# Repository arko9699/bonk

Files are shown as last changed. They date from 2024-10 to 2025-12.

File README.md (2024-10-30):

# bonk
 A 40% keyboard PCB project

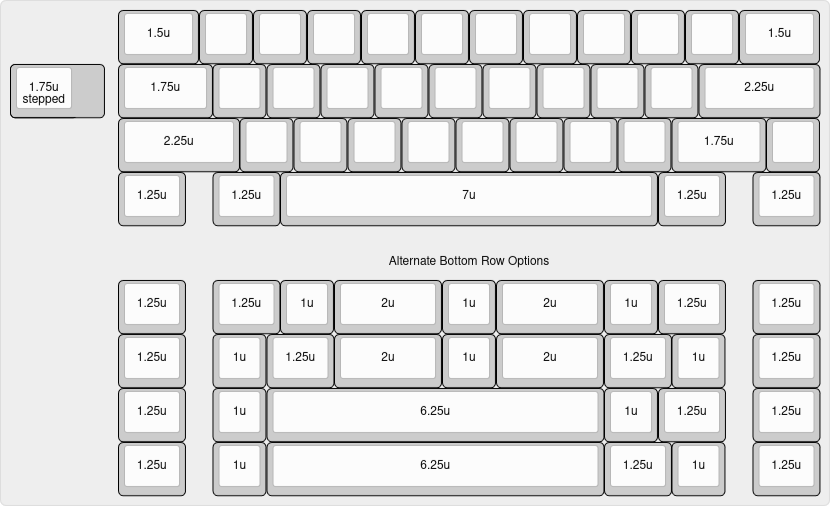
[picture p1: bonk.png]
layouts


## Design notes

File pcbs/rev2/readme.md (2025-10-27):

# PCB
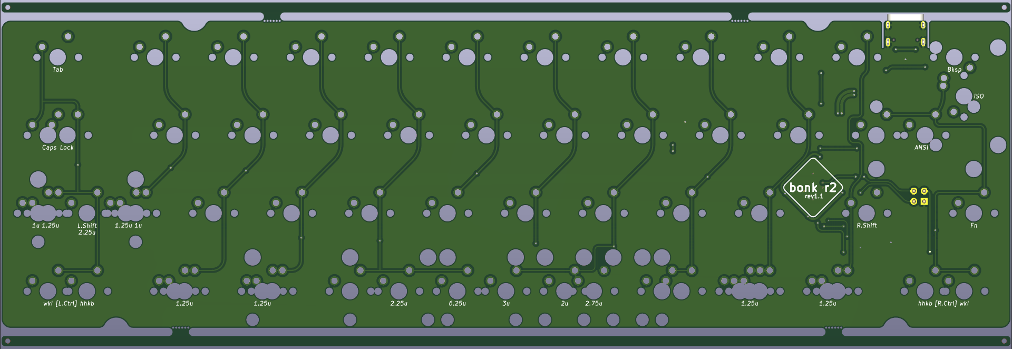
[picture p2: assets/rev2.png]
PCB


# Supported Layouts
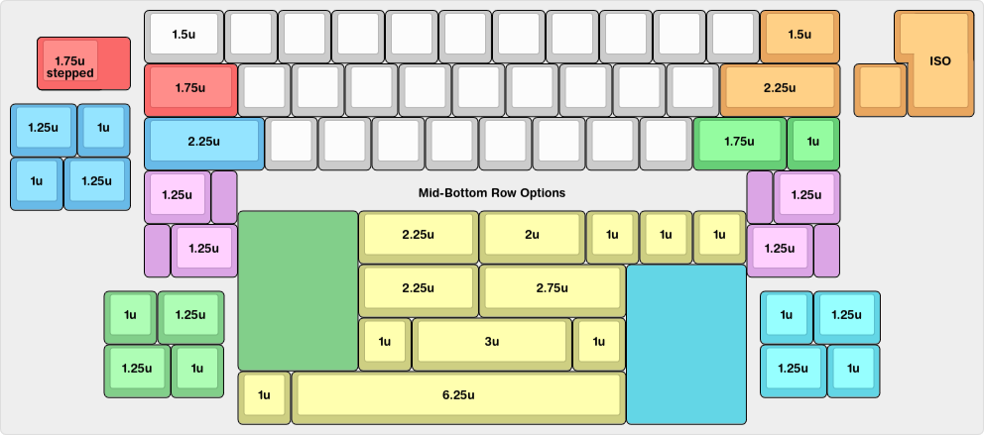
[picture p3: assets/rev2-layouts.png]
Supported Layouts


# Opening the project
* Atleast KiCAD 9.0.2 is required to open the project properly. Older versions of KiCAD will not work.
* [marbastlib](https://github.com/ebastler/marbastlib) was used for some of the footprints.

# Flashing
The following steps assume you have a PCB and the latest rev2 firmware downloaded.

Common Steps:
1. Plug in the PCB to the computer using an USB cable (either using uDB or directly)
2. Use [QMK Toolbox](https://qmk.fm/toolbox) on [Windows/Mac](https://docs.qmk.fm/newbs_flashing#flashing-your-keyboard-with-qmk-toolbox). Only CLI method is supported on [Linux](https://docs.qmk.fm/flashing#stm32-apm32-dfu). Select the 'bin' firmware file on your disk.
3. Hold down button for approximately 10 seconds to enter bootloader.
4. Select the 'Flash' option and wait for some time. The PCB should restart automatically after flashing and be ready to use.
5. Open [vial](https://vial.rocks/) in a USB HID supported browser (Chrome/Edge/Brave etc.) to modify your keymap.

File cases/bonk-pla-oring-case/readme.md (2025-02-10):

# What you'll need

1. The case (ofc)
2. Option A :
      * An MX switch plate (dxf given at the top directory may be used as is)
      * Gummy O-ring (similar to the ones used by [Bakeneko](https://github.com/kkatano/bakeneko-60)), recommended dimensions are 143mm ID, 3.53mm CS
     
   Option B : Use [EagleVee's Plateless O-Ring Kit](https://github.com/EagleVee/keyboards/tree/master/oring-plateless-kit) for a plateless experience

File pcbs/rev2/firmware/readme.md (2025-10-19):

# bonkr2

* Keyboard Maintainer: [Arko9699](https://github.com/arko9699)
* Hardware Supported: stm32f072
* Hardware Availability: [Github](https://github.com/arko9699/bonk/tree/main/pcbs/rev2)

Make example for this keyboard (after setting up your build environment):

    make arko/bonkr2:default

Flashing example for this keyboard:

    make arko/bonkr2:default:flash

See the [build environment setup](https://docs.qmk.fm/#/getting_started_build_tools) and the [make instructions](https://docs.qmk.fm/#/getting_started_make_guide) for more information. Brand new to QMK? Start with our [Complete Newbs Guide](https://docs.qmk.fm/#/newbs).

## Bootloader

Enter the bootloader in 3 ways:

* **Bootmagic reset**: Hold down the key at (0,0) in the matrix (usually the top left key or Escape) and plug in the keyboard
* **Physical reset button**: Briefly press the button on the back of the PCB - some may have pads you must short instead
* **Keycode in layout**: Press the key mapped to `QK_BOOT` if it is available

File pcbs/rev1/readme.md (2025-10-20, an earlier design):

# PCB
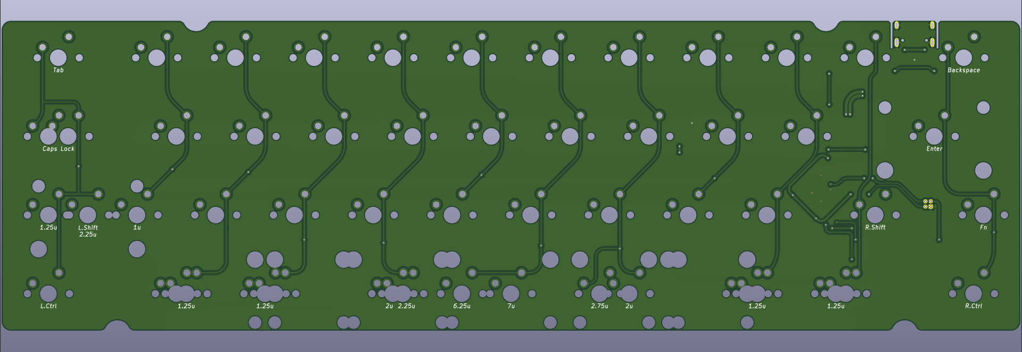
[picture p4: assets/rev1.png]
PCB


# Supported Layouts
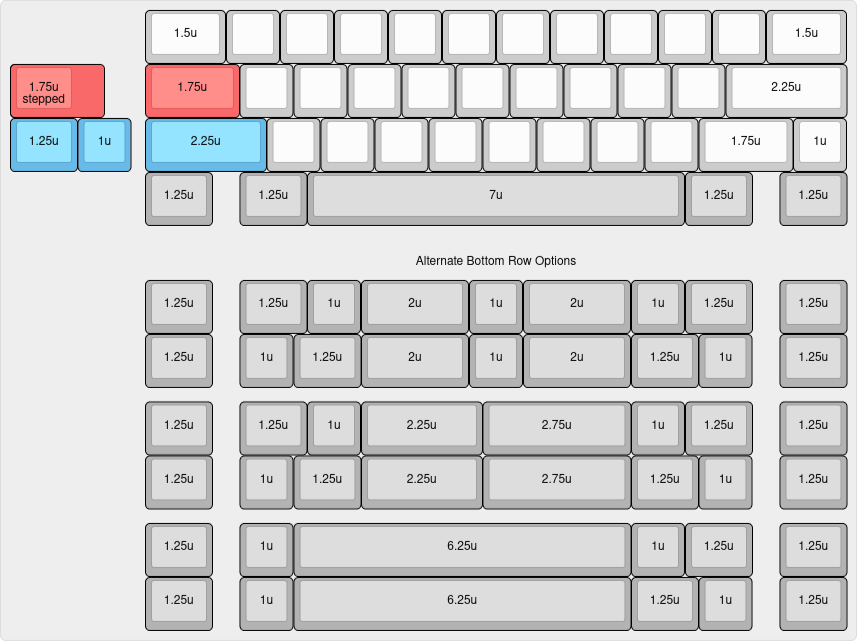
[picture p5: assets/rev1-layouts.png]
Supported Layouts


# Opening the project
* Atleast KiCAD 8.0.7 is required to open the project properly. Older versions of KiCAD will not work.
* [marbastlib](https://github.com/ebastler/marbastlib) was used for some of the footprints.

# Bill of Materials
|LCSC #  |Description|Value |Package |Amount|Comments |
|---|---|---|---|---|---|
|C15195  |Capacitor  |10nF |0402 |1 | |
|C1525 |Capacitor  |100nF |0402 |4 | |
|C15849  |Capacitor  |1uF |0603 |3 | |
|C19666  |Capacitor  |4.7uF |0603 |2 | |
|C25076  |Resistor |100Ω |0402 |1 | |
|C21190  |Resistor |1k Ω |0603 |1 |Added in rev1.1 |
|C23186  |Resistor |5.1kΩ |0603 |2 | |
|C25804  |Resistor |10kΩ |0603 |1 |Added in rev1.1 |
|C17629  |Resistor |330kΩ |0805 |1 |Added in rev1.1 |
|C17629  |Resistor |1MΩ |0805 |1 |Added in rev1.1 |
|C269104 |Fuse |500mA |0805 |1 | |
|C2988369|USB-C Port |USB-7010ASV |SMD/THT |1 | |
|C318884 |Push Button|TS-1187A |SMD |1 | |
|C5180249|ESD Prot.  |USBLC6-2SC6 |SOT-23-6|1 | |
|C81598  |Diode |1N4148W |SOD-123 |45 |Additional diode added in rev1.1|
|C81720  |MCU |STM32F072CBTx |LQFP-48 |1 | |
|C8545 |MOSFET |2N7002 |SOT-23  |1 |Added in rev1.1 |
|C5180249|Volt. Regu.|XC6206P332MR-G|SOT-23-3|1 | |
|C160404 |Opt. JST |SM04B-SRSS-TB |SMD |1 | | 

# Flashing
The following steps assume you have a PCB and the latest rev1.x firmware downloaded.

Common Steps:
1. Plug in the PCB to the computer using an USB cable (either using uDB or directly)
2. Hold down button for approximately 10 seconds to enter bootloader.
3. Use [QMK Toolbox](https://qmk.fm/toolbox) on [Windows/Mac](https://docs.qmk.fm/newbs_flashing#flashing-your-keyboard-with-qmk-toolbox). Only CLI method is supported on [Linux](https://docs.qmk.fm/flashing#stm32-apm32-dfu).
4. The PCB should restart automatically after flashing and be ready to use.
5. Open [vial](https://vial.rocks/) in a USB HID supported browser (Chrome/Edge/Brave etc.) to modify your keymap.

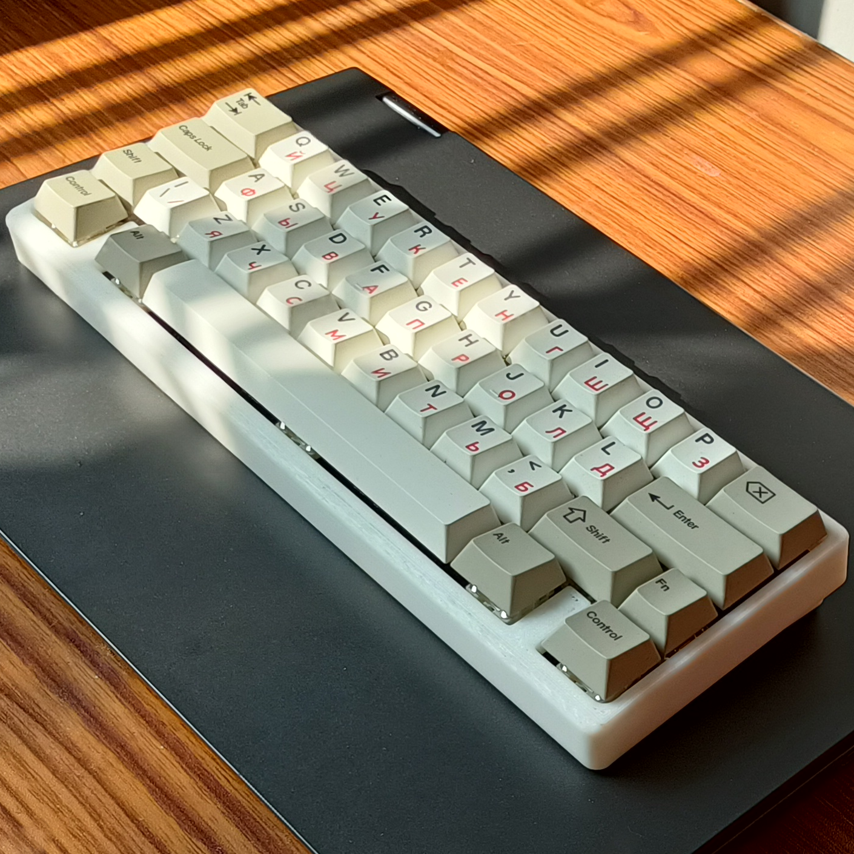
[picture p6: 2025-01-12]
assets/pic1-by-arko.png

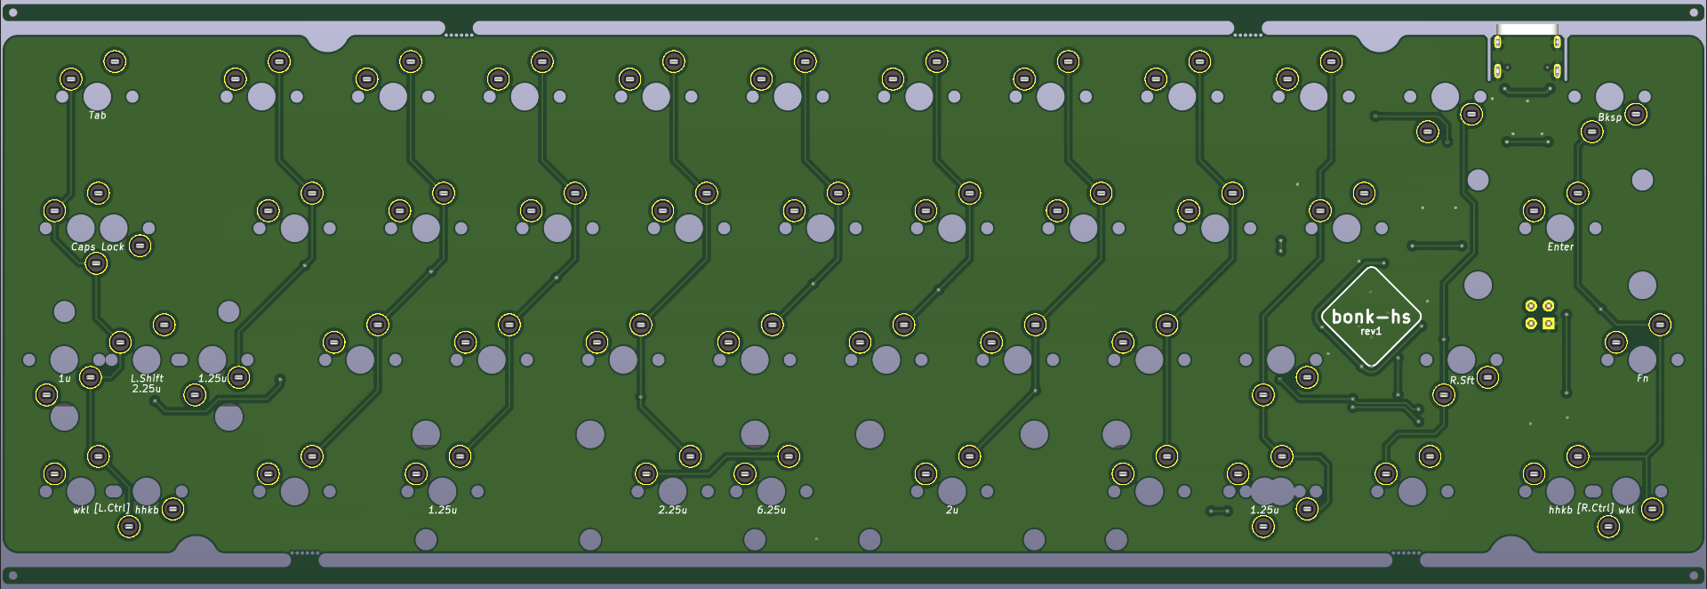
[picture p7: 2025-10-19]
assets/hotswap.png

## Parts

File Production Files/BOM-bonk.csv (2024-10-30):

Comment | Designator | Footprint | LCSC | Quantity
10n | C6 | C_0402_1005Metric | C15195 | 1
100n | C1,C10,C2,C4 | C_0402_1005Metric | C1525 | 4
Conn_01x04 | J1 | JST_SH_SM04B-SRSS-TB_1x04-1MP_P1.00mm_Horizontal | C160404 | 1
4.7u | C3,C5 | C_0603_1608Metric | C19666 | 2
10k | R1 | R_0603_1608Metric | C25744 | 1
SW_Push | SW1 | SW_Push_1P1T_XKB_TS-1187A | C318884 | 1
XC6206PxxxMR | U1 | SOT-23-3 | C5148692 | 1
4.7u | C7,C8,C9 | C_0603_1608Metric | C52923 | 3
1N4148W | D1,D10,D11,D12,D13,D14,D15,D16,D17,D18,D19,D2,D20,D21,D22,D23,D24,D25,D26,D27,D28,D29,D3,D30,D31,D32,D33,D34,D35,D36,D37,D38,D39,D4,D40,D5,D6,D7,D8,D9 | D_SOD-123 | C7420318 | 40
STM32F072CBTx | U2 | LQFP-48_7x7mm_P0.5mm | C81720 | 1
1N4148W | D41 | D_SOD-123 |  | 1
1N4148W | D42 | D_SOD-123 |  | 1
1N4148W | D44 | D_SOD-123 |  | 1
1N4148W | D43 | D_SOD-123 |  | 1

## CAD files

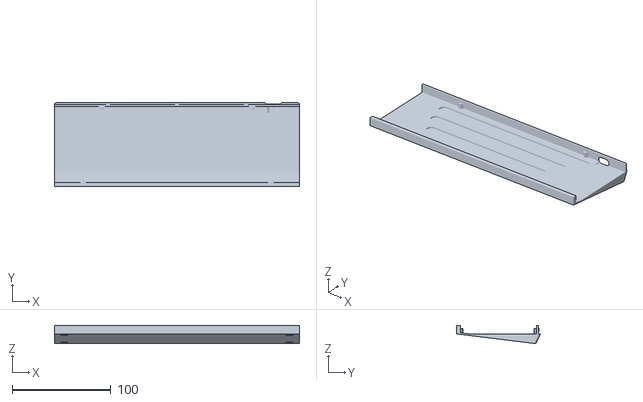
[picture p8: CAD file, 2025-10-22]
cases/bonk-pla-oring-case/bonk-pla-case-bottom.stl
248.6 x 84.9 x 18.6

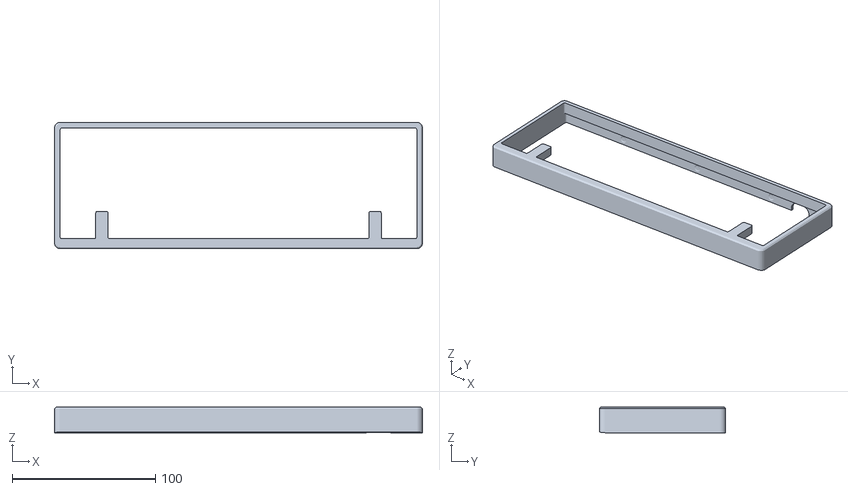
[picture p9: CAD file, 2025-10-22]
cases/bonk-pla-oring-case/bonk-pla-case-wkl-top.stl
256.6 x 88.2 x 17.8

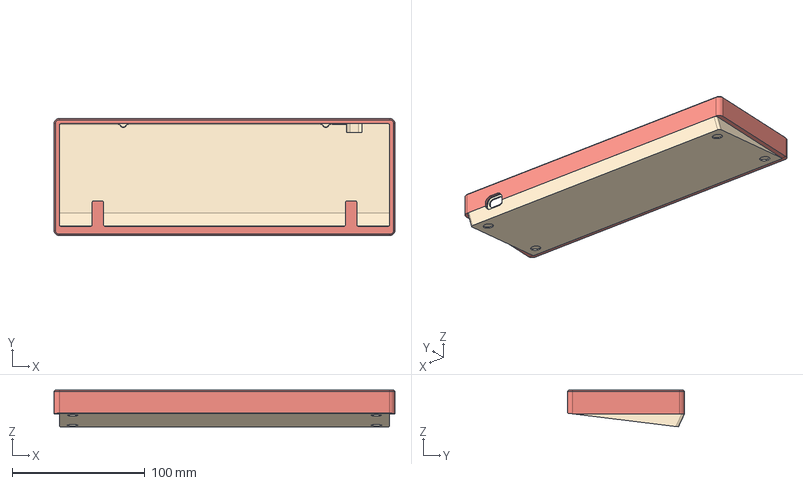
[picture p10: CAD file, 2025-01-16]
cases/bonk-pla-oring-case/bonk-pla-case.step
256.6 x 88.2 x 27.6 mm

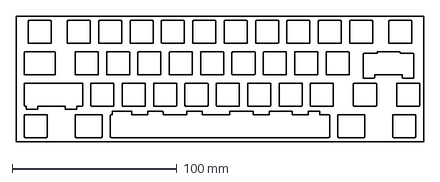
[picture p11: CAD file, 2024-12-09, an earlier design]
pcbs/rev1/bonk-plate-template.dxf
247.7 x 76.2 mm

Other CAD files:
cases/bonk-pla-oring-case/bonk-pla-case-hhkb-top.stl

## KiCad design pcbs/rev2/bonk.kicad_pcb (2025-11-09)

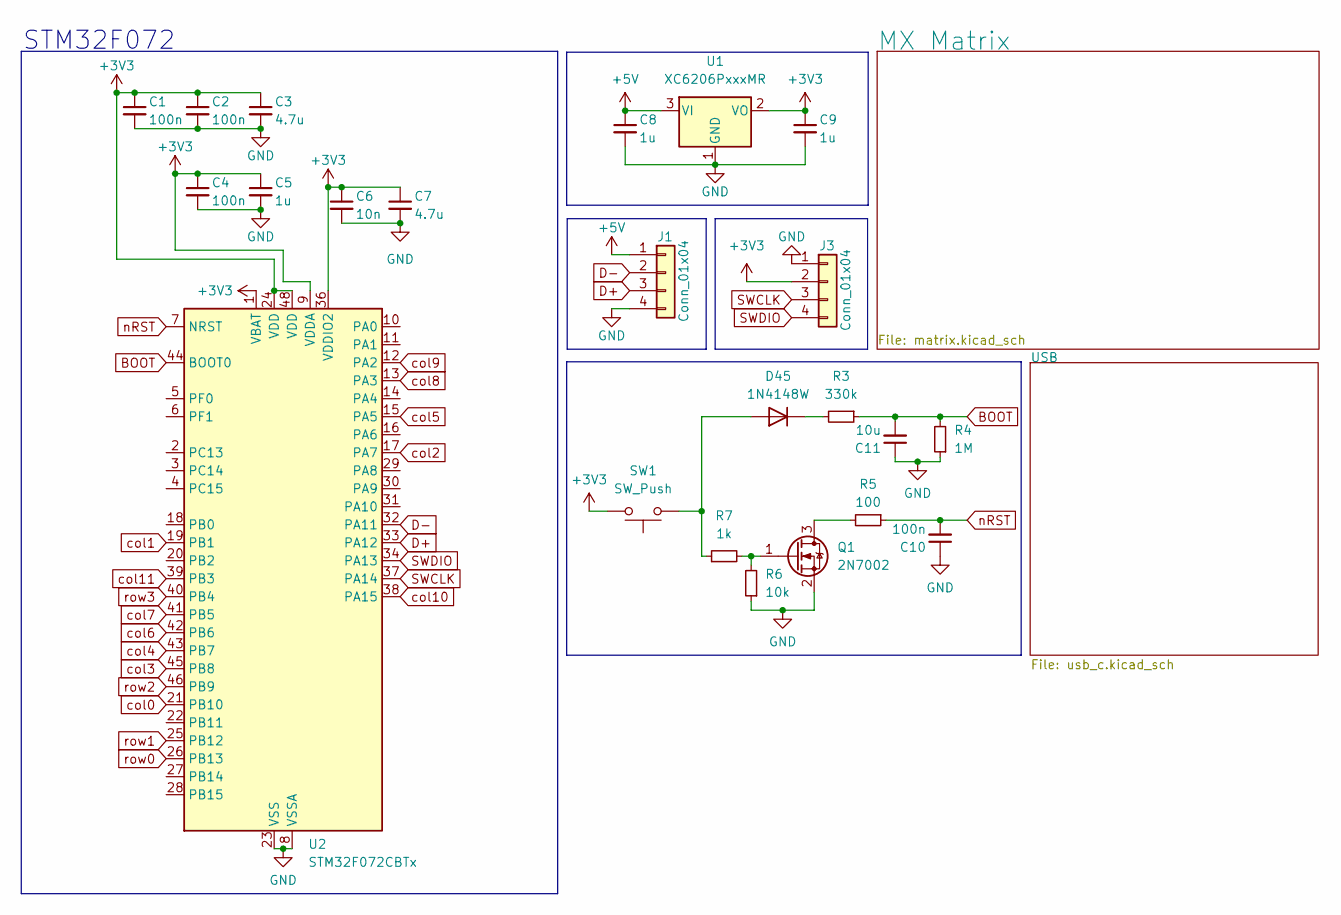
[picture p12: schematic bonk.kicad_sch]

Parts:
C1, C2, C4, C10: 100n; C_0402_1005Metric
C3, C7: 4.7u; C_0603_1608Metric
C5, C8, C9: 1u; C_0603_1608Metric
C6: 10n; C_0402_1005Metric
C11: 10u; C_0603_1608Metric
D45: 1N4148W; D_SOD-123
J1: Conn_01x04; JST_SH_SM04B-SRSS-TB_1x04-1MP_P1.00mm_Horizontal
J3: Conn_01x04; PinHeader_2x02_P2.54mm_Vertical
Q1: 2N7002; SOT-23
R3: 330k; R_0805_2012Metric
R4: 1M; R_0805_2012Metric
R5: 100; R_0402_1005Metric_Pad0.72x0.64mm_HandSolder
R6: 10k; R_0603_1608Metric_Pad0.98x0.95mm_HandSolder
R7: 1k; R_0603_1608Metric
SW1: SW_Push; SW_Push_1P1T_XKB_TS-1187A
U1: XC6206PxxxMR; SOT-23-3
U2: STM32F072CBTx; LQFP-48_7x7mm_P0.5mm

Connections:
+3V3: C1.1, C2.1, C3.1, C4.1, C5.1, C6.1, C7.1, C9.1, J3.2, SW1.2, U1.2 (VO), U2.1 (VBAT), U2.9 (VDDA), U2.24 (VDD), U2.36 (VDDIO2), U2.48 (VDD)
+5V: C8.1, J1.1, U1.3 (VI); also elsewhere on the board
BOOT: C11.2, R3.1, R4.2, U2.44 (BOOT0)
D+: J1.3, U2.33 (PA12); also elsewhere on the board
D-: J1.2, U2.32 (PA11); also elsewhere on the board
GND: C1.2, C2.2, C3.2, C4.2, C5.2, C6.2, C7.2, C8.2, C9.2, C10.1, C11.1, J1.4, J3.1, Q1.2 (S), R4.1, R6.1, U1.1 (GND), U2.8 (VSSA), U2.23 (VSS), U2.35 (VSS), U2.47 (VSS); also elsewhere on the board
unnamed: D45.2 (A), R7.1, SW1.1
unnamed: D45.1 (K), R3.2
unnamed: Q1.3 (D), R5.2
unnamed: Q1.1 (G), R6.2, R7.2
SWCLK: J3.3, U2.37 (PA14)
SWDIO: J3.4, U2.34 (PA13)
col0: U2.21 (PB10); also elsewhere on the board
col1: U2.19 (PB1); also elsewhere on the board
col2: U2.17 (PA7); also elsewhere on the board
col3: U2.45 (PB8); also elsewhere on the board
col4: U2.43 (PB7); also elsewhere on the board
col5: U2.15 (PA5); also elsewhere on the board
col6: U2.42 (PB6); also elsewhere on the board
col7: U2.41 (PB5); also elsewhere on the board
col8: U2.13 (PA3); also elsewhere on the board
col9: U2.12 (PA2); also elsewhere on the board
col10: U2.38 (PA15); also elsewhere on the board
col11: U2.39 (PB3); also elsewhere on the board
nRST: C10.2, R5.1, U2.7 (NRST)
row0: U2.26 (PB13); also elsewhere on the board
row1: U2.25 (PB12); also elsewhere on the board
row2: U2.46 (PB9); also elsewhere on the board
row3: U2.40 (PB4); also elsewhere on the board

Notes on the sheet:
STM32F072

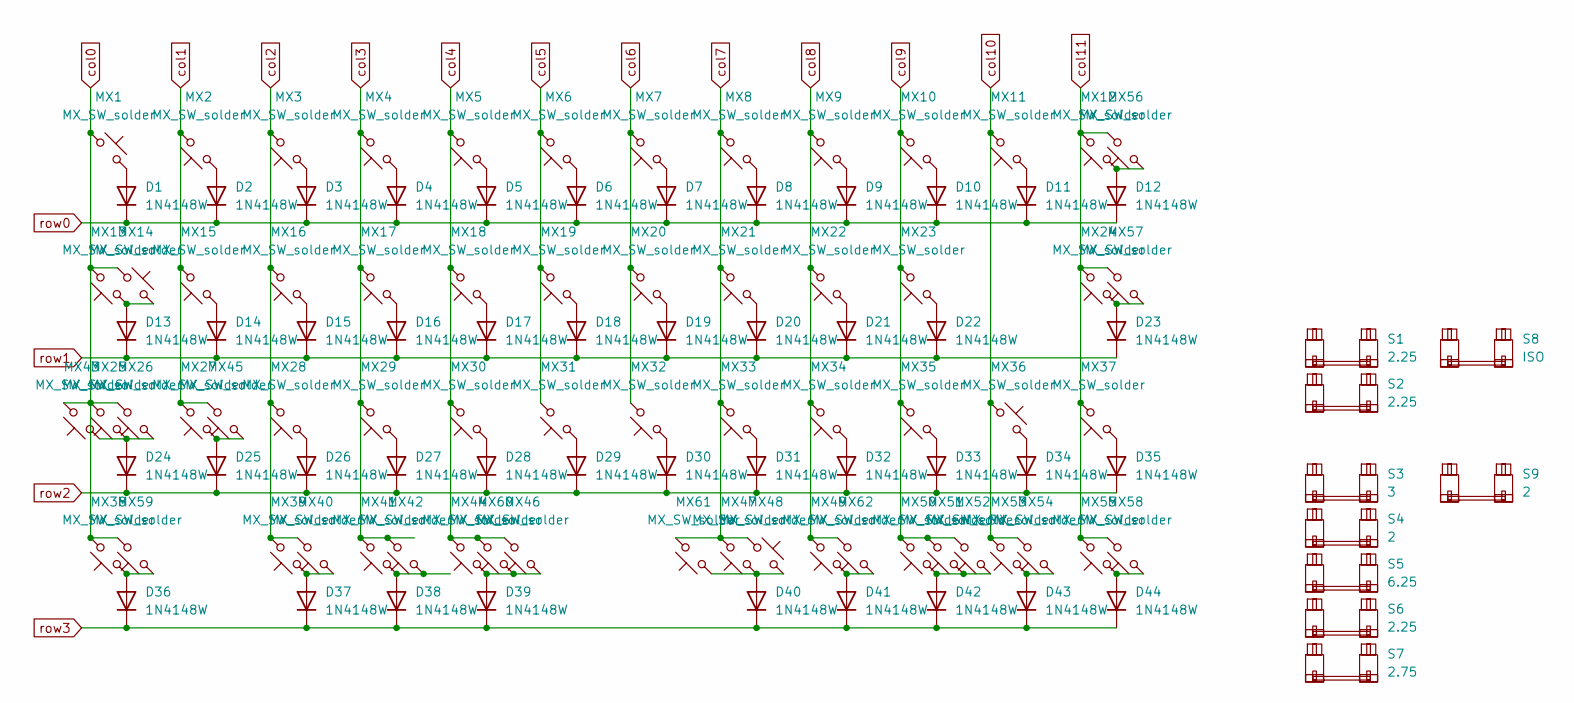
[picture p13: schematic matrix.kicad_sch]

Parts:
D1, D2, D3, D4, D5, D6, D7, D8, D9, D10, D11, D12, D13, D14, D15, D16, D17, D18, D19, D20, D21, D22, D23, D24, D25, D26, D27, D28, D29, D30, D31, D32, D33, D34, D35, D36, D37, D38, D39, D40, D41, D42, D43, D44: 1N4148W; D_SOD-123
MX1, MX12: MX_SW_solder; SW_MX_1.5u
MX2, MX3, MX4, MX5, MX6, MX7, MX8, MX9, MX10, MX11, MX15, MX16, MX17, MX18, MX19, MX20, MX21, MX22, MX23, MX24, MX25, MX27, MX28, MX29, MX30, MX31, MX32, MX33, MX34, MX35, MX37, MX40, MX42, MX43, MX44, MX46, MX47, MX48, MX49, MX51, MX52, MX54, MX56, MX57, MX60, MX61, MX62: MX_SW_solder; SW_MX_1u
MX13, MX36: MX_SW_solder; SW_MX_1.75u
MX14: MX_SW_solder; SW_MX_1.75u_STP_1.25
MX26, MX38, MX39, MX41, MX45, MX50, MX53, MX55, MX58, MX59: MX_SW_solder; SW_MX_1.25u
S1, S2, S6: 2.25; STAB_MX_2.25u
S3: 3; STAB_MX_3u
S4, S9: 2; STAB_MX_2u
S5: 6.25; STAB_MX_6.25u
S7: 2.75; STAB_MX_2.75u
S8: ISO; STAB_MX_ISO

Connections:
unnamed: D1.2 (A), MX1.2
unnamed: D2.2 (A), MX2.1
unnamed: D3.2 (A), MX3.1
unnamed: D4.2 (A), MX4.1
unnamed: D5.2 (A), MX5.1
unnamed: D6.2 (A), MX6.1
unnamed: D7.2 (A), MX7.1
unnamed: D8.2 (A), MX8.1
unnamed: D9.2 (A), MX9.1
unnamed: D10.2 (A), MX10.1
unnamed: D11.2 (A), MX11.1
unnamed: D12.2 (A), MX12.1, MX56.1
unnamed: D13.2 (A), MX13.1, MX14.2
unnamed: D14.2 (A), MX15.1
unnamed: D15.2 (A), MX16.1
unnamed: D16.2 (A), MX17.1
unnamed: D17.2 (A), MX18.1
unnamed: D18.2 (A), MX19.1
unnamed: D19.2 (A), MX20.1
unnamed: D20.2 (A), MX21.1
unnamed: D21.2 (A), MX22.1
unnamed: D22.2 (A), MX23.1
unnamed: D23.2 (A), MX24.1, MX57.1
unnamed: D24.2 (A), MX25.1, MX26.1, MX43.1
unnamed: D25.2 (A), MX27.1, MX45.1
unnamed: D26.2 (A), MX28.1
unnamed: D27.2 (A), MX29.1
unnamed: D28.2 (A), MX30.1
unnamed: D29.2 (A), MX31.1
unnamed: D30.2 (A), MX32.1
unnamed: D31.2 (A), MX33.1
unnamed: D32.2 (A), MX34.1
unnamed: D33.2 (A), MX35.1
unnamed: D34.2 (A), MX36.2
unnamed: D35.2 (A), MX37.1
unnamed: D36.2 (A), MX38.1, MX59.1
unnamed: D37.2 (A), MX39.1, MX40.1
unnamed: D38.2 (A), MX41.1, MX42.1
unnamed: D39.2 (A), MX44.1, MX46.1, MX60.1
unnamed: D40.2 (A), MX47.1, MX48.2, MX61.1
unnamed: D41.2 (A), MX49.1, MX62.1
unnamed: D42.2 (A), MX50.1, MX51.1, MX52.1
unnamed: D43.2 (A), MX53.1, MX54.1
unnamed: D44.2 (A), MX55.1, MX58.1
col0: MX1.1, MX13.2, MX14.1, MX25.2, MX26.2, MX38.2, MX43.2, MX59.2; also elsewhere on the board
col1: MX2.2, MX15.2, MX27.2, MX45.2; also elsewhere on the board
col2: MX3.2, MX16.2, MX28.2, MX39.2, MX40.2; also elsewhere on the board
col3: MX4.2, MX17.2, MX29.2, MX41.2, MX42.2; also elsewhere on the board
col4: MX5.2, MX18.2, MX30.2, MX44.2, MX46.2, MX60.2; also elsewhere on the board
col5: MX6.2, MX19.2, MX31.2; also elsewhere on the board
col6: MX7.2, MX20.2, MX32.2; also elsewhere on the board
col7: MX8.2, MX21.2, MX33.2, MX47.2, MX48.1, MX61.2; also elsewhere on the board
col8: MX9.2, MX22.2, MX34.2, MX49.2, MX62.2; also elsewhere on the board
col9: MX10.2, MX23.2, MX35.2, MX50.2, MX51.2, MX52.2; also elsewhere on the board
col10: MX11.2, MX36.1, MX53.2, MX54.2; also elsewhere on the board
col11: MX12.2, MX24.2, MX37.2, MX55.2, MX56.2, MX57.2, MX58.2; also elsewhere on the board
row0: D1.1 (K), D2.1 (K), D3.1 (K), D4.1 (K), D5.1 (K), D6.1 (K), D7.1 (K), D8.1 (K), D9.1 (K), D10.1 (K), D11.1 (K), D12.1 (K); also elsewhere on the board
row1: D13.1 (K), D14.1 (K), D15.1 (K), D16.1 (K), D17.1 (K), D18.1 (K), D19.1 (K), D20.1 (K), D21.1 (K), D22.1 (K), D23.1 (K); also elsewhere on the board
row2: D24.1 (K), D25.1 (K), D26.1 (K), D27.1 (K), D28.1 (K), D29.1 (K), D30.1 (K), D31.1 (K), D32.1 (K), D33.1 (K), D34.1 (K), D35.1 (K); also elsewhere on the board
row3: D36.1 (K), D37.1 (K), D38.1 (K), D39.1 (K), D40.1 (K), D41.1 (K), D42.1 (K), D43.1 (K), D44.1 (K); also elsewhere on the board

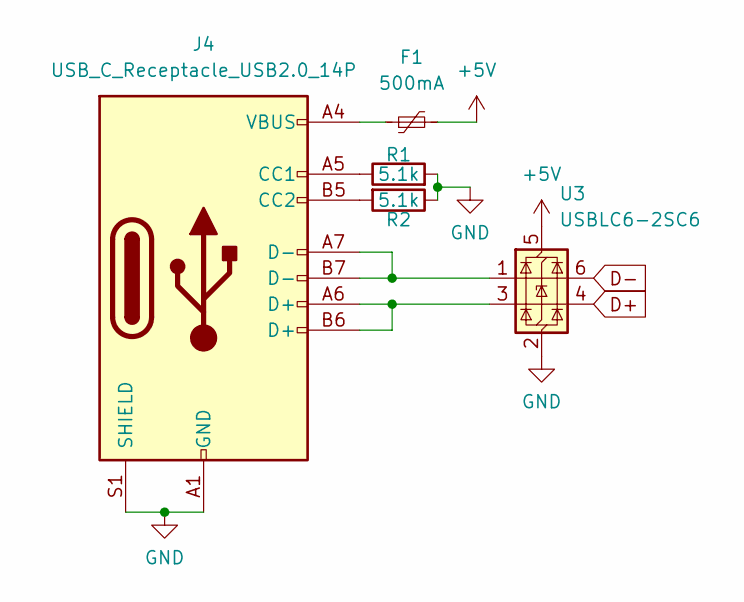
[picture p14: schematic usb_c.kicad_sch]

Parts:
F1: 500mA; Fuse_0805_2012Metric
J4: USB_C_Receptacle_USB2.0_14P; USB_C_Receptacle_G-Switch_GT-USB-7010ASV
R1, R2: 5.1k; R_0603_1608Metric
U3: USBLC6-2SC6; SOT-23-6

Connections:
+5V: F1.2, U3.5 (VBUS); also elsewhere on the board
D+: U3.4 (I/O2); also elsewhere on the board
D-: U3.6 (I/O1); also elsewhere on the board
GND: J4.A1 (GND), J4.A12 (GND), J4.B1 (GND), J4.B12 (GND), J4.S1 (SHIELD), R1.2, R2.1, U3.2 (GND); also elsewhere on the board
unnamed: F1.1, J4.A4 (VBUS), J4.A9 (VBUS), J4.B4 (VBUS), J4.B9 (VBUS)
unnamed: J4.A5 (CC1), R1.1
unnamed: J4.B5 (CC2), R2.2
unnamed: J4.A6 (D+), J4.B6 (D+), U3.3 (I/O2)
unnamed: J4.A7 (D-), J4.B7 (D-), U3.1 (I/O1)

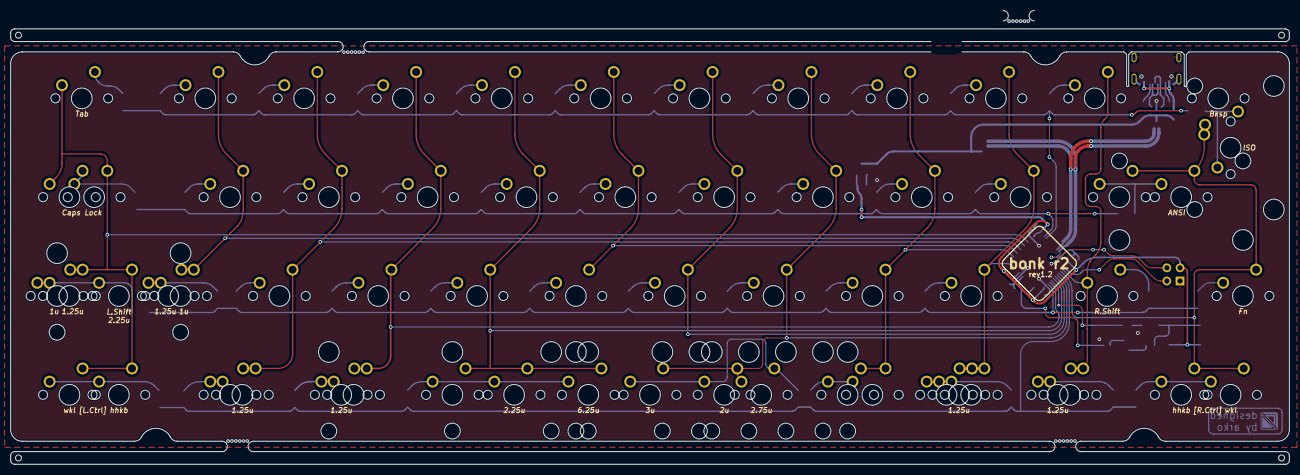
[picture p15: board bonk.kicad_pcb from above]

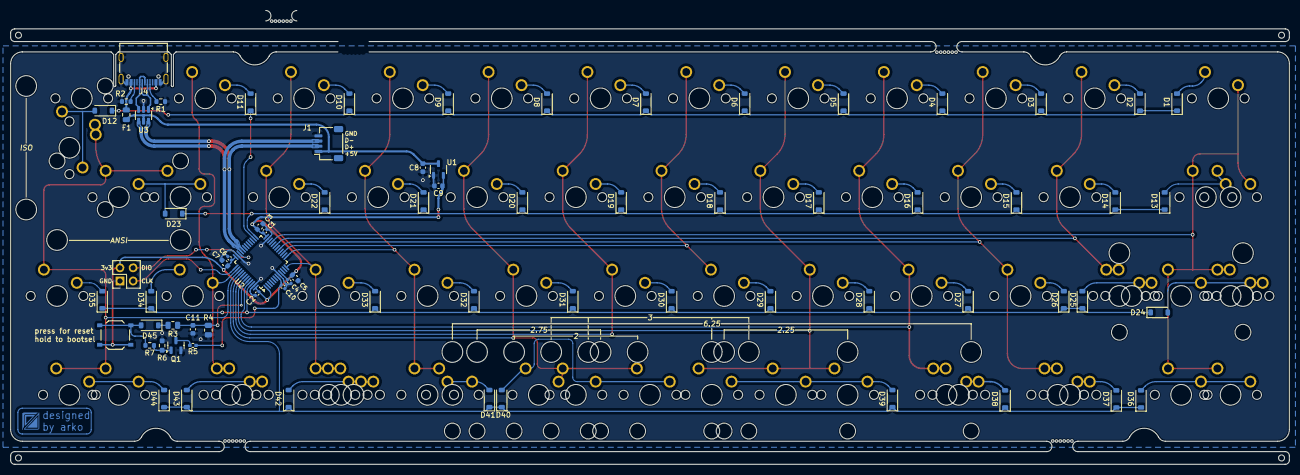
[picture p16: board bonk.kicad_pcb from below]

Board: 2 copper layers, 246.5 x 87.5 mm, 143 parts (72 on the bottom side), 78 nets.

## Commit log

2024-10-30 added prod files
    [BOM-bonk.csv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]
2024-10-30 renamed directory
    [bonk-CuBottom.gbr, bonk-CuTop.gbr, bonk-EdgeCuts.gbr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]
2024-11-20 rev01a
    added mousebites near usb connector to make removal easier (this is a destructive operation!)
    repositioned usb components to reduce number of vias and add space for mousebites
    [BOM-bonk.csv, bonk.kicad_pcb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]
2024-12-02 Change USB Connector
    [bonk.kicad_pcb, usb_c.kicad_sch]
2024-12-09 Added reference plate file.
    [bonk-plate-template.dxf]
2024-12-23 Added Part Name for USB connector
2025-01-16 aesthetic fixes to bonk-pla-case
    [bonk-pla-case-bottom.stl, bonk-pla-case-top.stl, bonk-pla-case.step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]
2025-01-27 rev1.1
    1. Changed reset/boot circuitry to have single-button Reset/Boot functionality.
    2. Removed mounting holes
    [bonk.kicad_pcb, bonk.kicad_sch, usb_c.kicad_sch]
2025-02-10 restructure of files
    moved around files in accordance with logical placements. no new files were added neither older files were removed.
    [bonk.kicad_pcb, bonk.kicad_sch, matrix.kicad_sch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]
2025-10-19 rev2 and hs-wip
    Restructured file paths and added pcb files for rev2
    [bonk-plate-template.dxf, bonk.kicad_pcb, bonk.kicad_sch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]
2025-10-22 Updated case files for R2
    [bonk-pla-case-bottom.stl, bonk-pla-case-hhkb-top.stl, bonk-pla-case-top.stl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]
2025-11-09 Added 2u stab mount points for 3u Spacebar option
    [bonk.kicad_pcb, matrix.kicad_sch]
2025-12-01 WIP of a wireless, hotswap edition of the bonk
    [bonk.kicad_pcb, bonk.kicad_sch, matrix.kicad_sch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]
2025-12-07 removed due to lack of personal interest
    [bonk.kicad_pcb, bonk.kicad_sch, matrix.kicad_sch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]
